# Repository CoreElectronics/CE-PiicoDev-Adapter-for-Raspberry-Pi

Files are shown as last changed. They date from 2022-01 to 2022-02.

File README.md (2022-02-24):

# PiicoDev® Adapter for Raspberry Pi

*This is the hardware repo for the [PiicoDev® Adapter for Raspberry Pi](https://core-electronics.com.au/catalog/product/view/sku/CE07690)*

The PiicoDev® Adapter for Raspberry Pi is a great way to connect sensors to your Raspberry Pi. Use the on-board PiicoDev connectors to quickly and easily connect with the [PiicoDev](https://core-electronics.com.au/piicodev) family of sensor modules without soldering.

**Features**

- Rapid prototyping with solderless connections
- Other useful pins are broken out
- PiicoDev connector, compatible with Qwiic and STEMMA QT (3.3V only)
- Manufactured and [supported](https://core-electronics.com.au/contacts/) in Australia by Core Electronics

**Technical Details**

- Dimensions: 22x51mm
- PiicoDev connector pinout:
  -1 GND
  -2 3.3V
  -3 SDA
  -4 SCL
- The I2C Bus presented at the PiicoDev connector contains series 120Ohm resistances to prevent destructive signal undershoot. Refer to the schematic for more information. To operate without these series resistors, users may connect directly to the GPIO instead.

# License
This project is open source - please review the LICENSE.md file for further licensing information.

If you have any technical questions, or concerns about licensing, please contact technical support on the [Core Electronics forums](https://forum.core-electronics.com.au/).

---
*\"PiicoDev" is a registered trademark of Core Electronics Pty Ltd*

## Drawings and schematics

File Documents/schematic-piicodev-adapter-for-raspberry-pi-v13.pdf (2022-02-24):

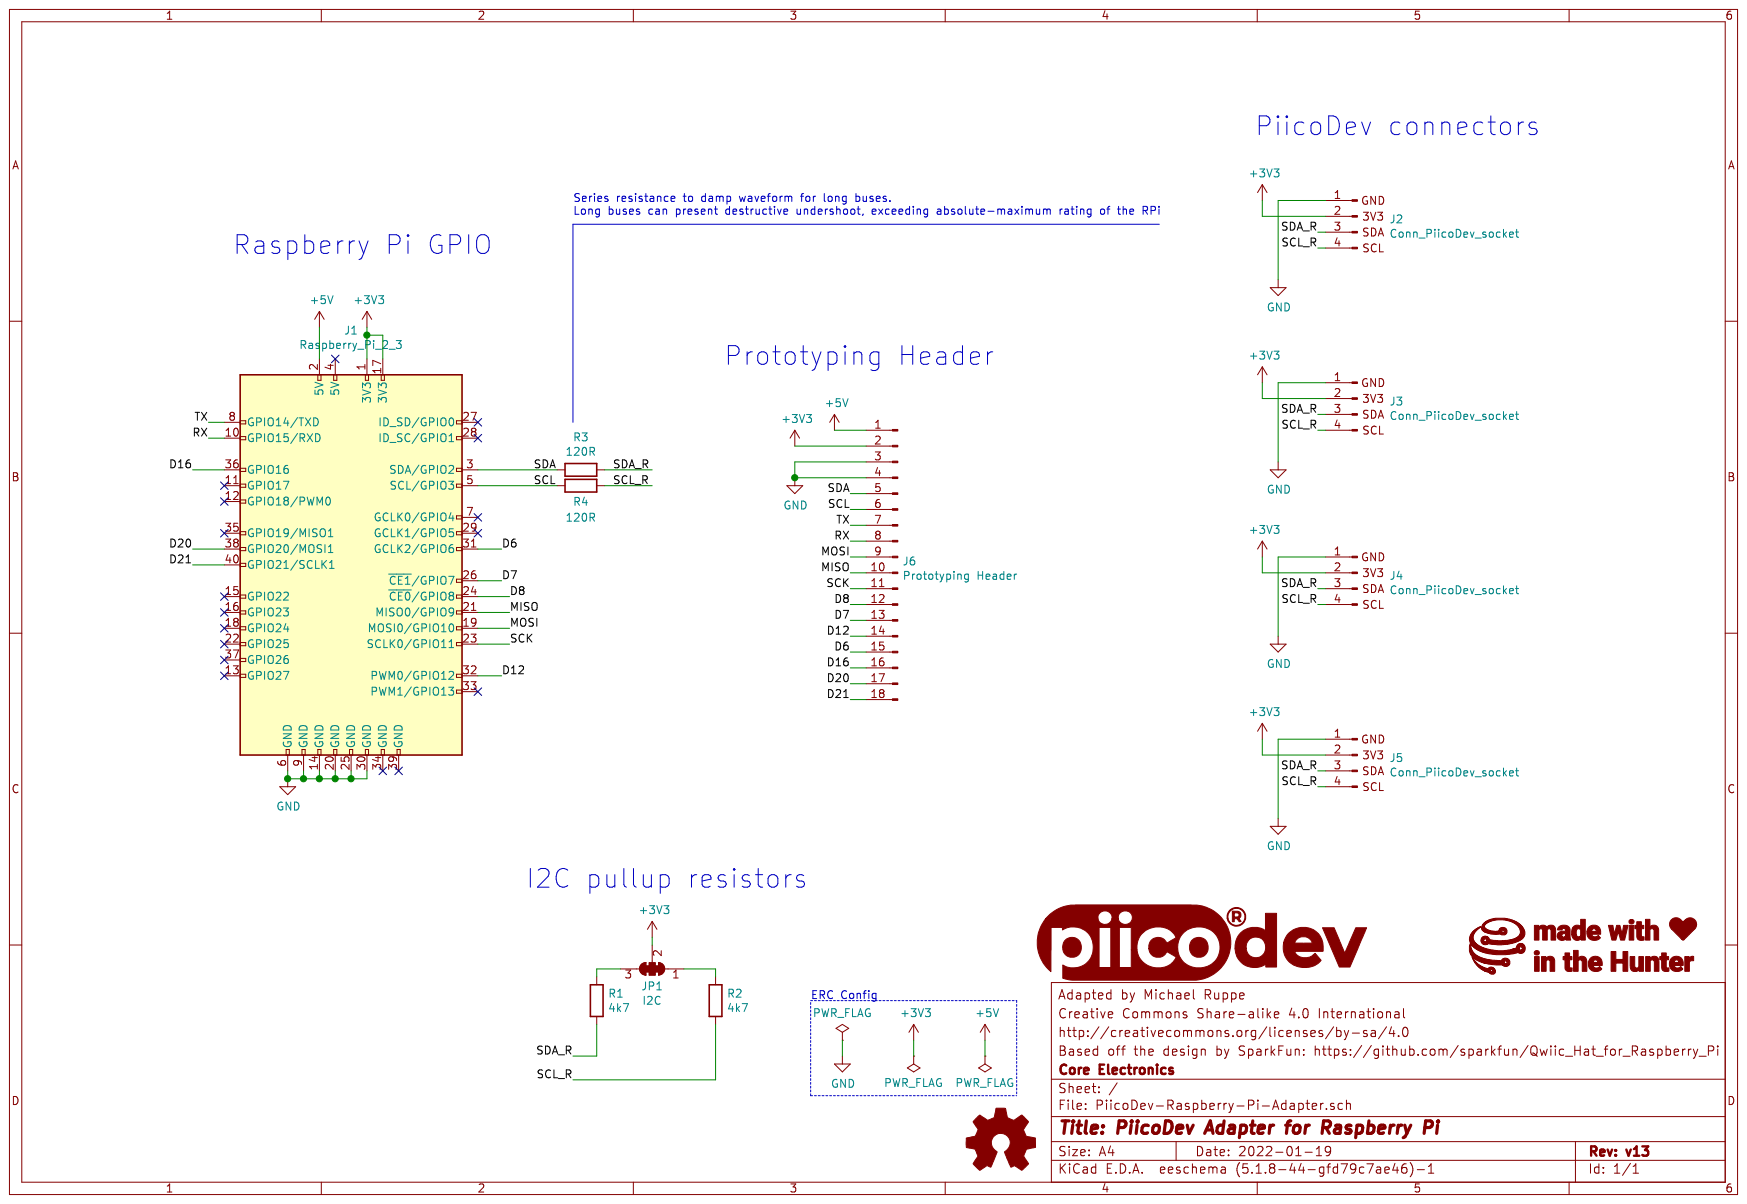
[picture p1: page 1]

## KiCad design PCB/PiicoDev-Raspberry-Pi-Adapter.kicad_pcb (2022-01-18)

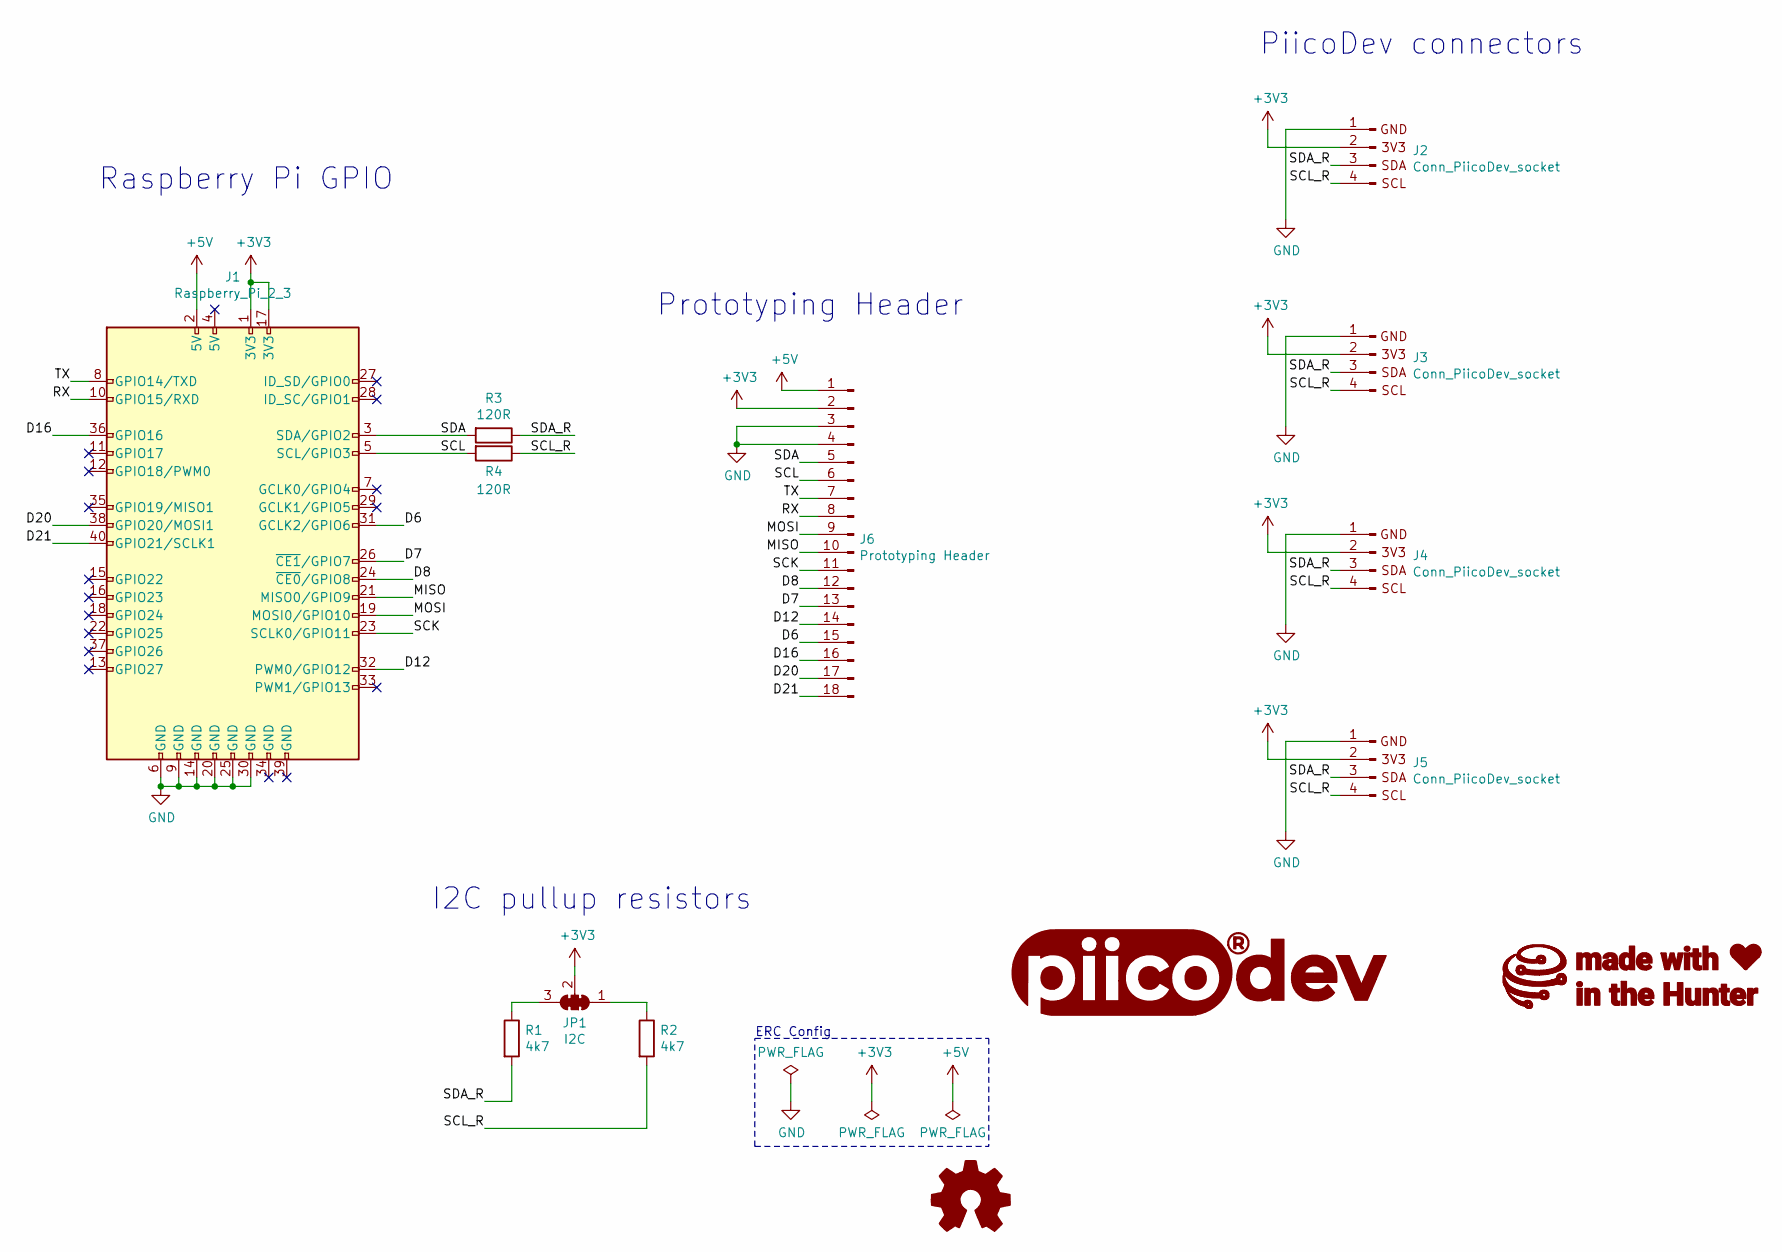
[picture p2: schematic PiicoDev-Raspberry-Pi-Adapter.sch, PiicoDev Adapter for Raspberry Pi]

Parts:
G1: LOGO_PiicoDev; piicodev_logo_10.2x2.5mm
G2: LOGO_CoreElectronics_made-with-love; piicodev_logo_10.2x2.5mm
J1: Raspberry_Pi_2_3; PinSocket_2x20_P2.54mm_Vertical_SMD_With_Post
J2, J3, J4, J5: Conn_PiicoDev_socket; JST_SH_SM04B-SRSS-TB_1x04-1MP_P1.00mm_Horizontal
J6: Prototyping Header; PinHeader_1x18_P2.54mm_Vertical
JP1: I2C; SolderJumper-3_P1.3mm_Closed_RoundedPad1.0x1.5mm_NumberLabe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
LOGO1: Logo_Open_Hardware_Small; oshw_3.9x3.5mm
R1, R2: 4k7; R_0402_1005Metric
R3, R4: 120R; R_0402_1005Metric

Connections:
+3V3: J1.1 (3V3), J1.17 (3V3), J2.2, J3.2, J4.2, J5.2, J6.2, JP1.2 (C)
+5V: J1.2 (5V), J6.1
/D6: J1.31 (GCLK2/GPIO6), J6.15
/D7: J1.26 (~CE1~/GPIO7), J6.13
/D8: J1.24 (~CE0~/GPIO8), J6.12
/D12: J1.32 (PWM0/GPIO12), J6.14
/D16: J1.36 (GPIO16), J6.16
/D20: J1.38 (GPIO20/MOSI1), J6.17
/D21: J1.40 (GPIO21/SCLK1), J6.18
/MISO: J1.21 (MISO0/GPIO9), J6.10
/MOSI: J1.19 (MOSI0/GPIO10), J6.9
/RX: J1.10 (GPIO15/RXD), J6.8
/SCK: J1.23 (SCLK0/GPIO11), J6.11
/SCL: J1.5 (SCL/GPIO3), J6.6, R4.2
/SCL_R: J2.4, J3.4, J4.4, J5.4, R2.2, R4.1
/SDA: J1.3 (SDA/GPIO2), J6.5, R3.2
/SDA_R: J2.3, J3.3, J4.3, J5.3, R1.2, R3.1
/TX: J1.8 (GPIO14/TXD), J6.7
GND: J1.6 (GND), J1.9 (GND), J1.14 (GND), J1.20 (GND), J1.25 (GND), J1.30 (GND), J2.1, J3.1, J4.1, J5.1, J6.3, J6.4
unnamed: JP1.1 (A), R2.1
unnamed: JP1.3 (B), R1.1

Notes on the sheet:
Prototyping Header
PiicoDev connectors
Raspberry Pi GPIO
I2C pullup resistors
ERC Config

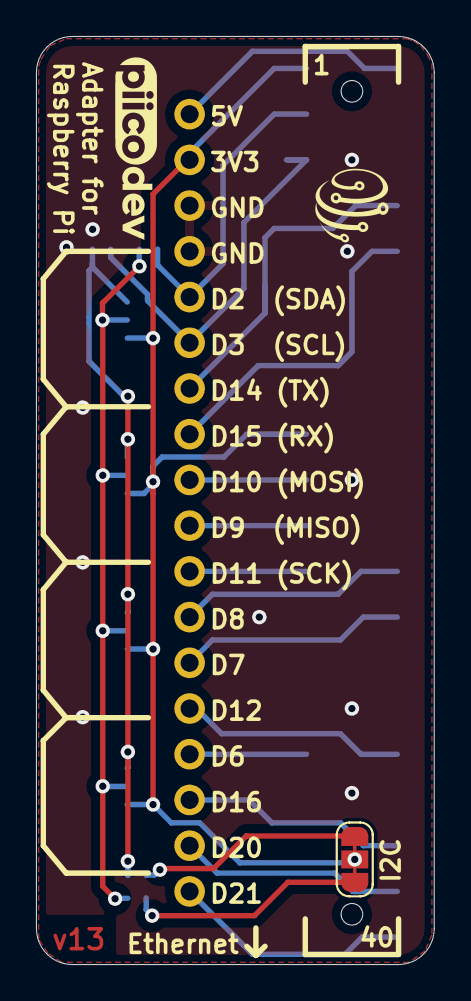
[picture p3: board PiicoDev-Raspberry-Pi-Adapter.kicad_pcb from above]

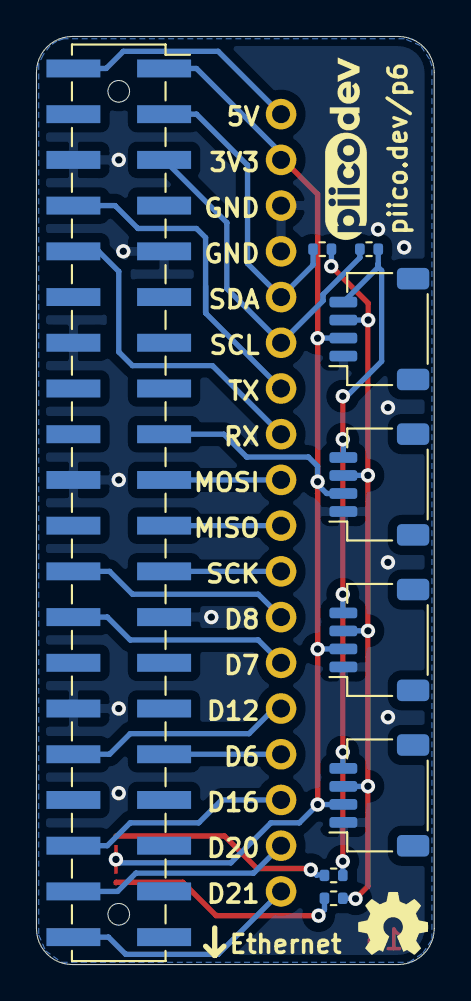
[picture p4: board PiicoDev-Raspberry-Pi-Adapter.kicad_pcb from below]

Board: 2 copper layers, 22.1 x 51.6 mm, 14 parts (11 on the bottom side), 21 nets.

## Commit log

2021-04-16 Add Logo to silkscreen
    [PiicoDev-Raspberry-Pi-Adapter.kicad_pcb, PiicoDev-Raspberry-Pi-Adapter.sch]
2021-06-28 Bump to v11 - update header footprint to include post-holes
    [PiicoDev-Raspberry-Pi-Adapter.kicad_pcb, PiicoDev-Raspberry-Pi-Adapter.sch]
2021-10-29 Add 120R to SCL & SDA. Improve silk screen.
    [PiicoDev-Raspberry-Pi-Adapter.kicad_pcb, PiicoDev-Raspberry-Pi-Adapter.sch]
2022-01-18 v13
    Add Raspberry Pi connector pin numbers to silk screen
    Update solder jumper with thinner cut trace
    Fix PiicoDev connector ground connection
    [PiicoDev-Raspberry-Pi-Adapter.kicad_pcb, PiicoDev-Raspberry-Pi-Adapter.sch]
2022-01-18 Change date
    [PiicoDev-Raspberry-Pi-Adapter.kicad_pcb, PiicoDev-Raspberry-Pi-Adapter.sch]
2022-02-24 update pdf to v13
    [PiicoDev-Raspberry-Pi-Adapter.sch]

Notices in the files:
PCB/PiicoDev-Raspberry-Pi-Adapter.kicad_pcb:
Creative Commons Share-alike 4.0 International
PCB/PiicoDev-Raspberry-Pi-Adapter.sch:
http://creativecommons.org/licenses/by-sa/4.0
